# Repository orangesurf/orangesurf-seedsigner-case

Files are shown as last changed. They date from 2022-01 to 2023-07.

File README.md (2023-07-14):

# OrangeSurf SeedSigner Case
Case for the seed signer DIY bitcoin hardware wallet by OrangeSurf (https://orange.surf)

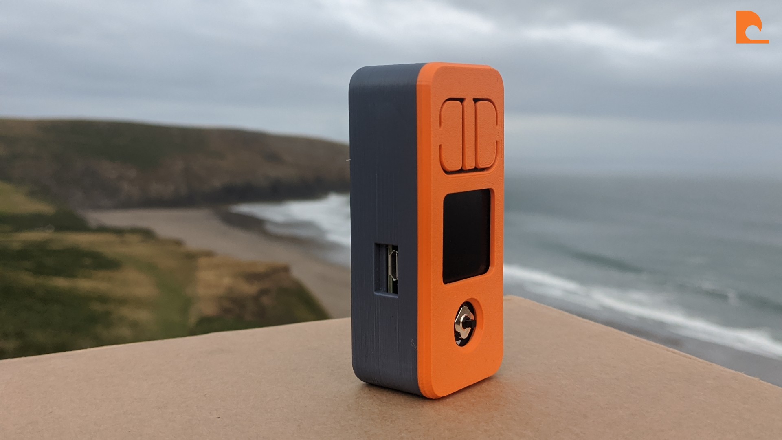
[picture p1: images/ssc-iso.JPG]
ssc-iso


## Donations 
Donations are accepted in bitcoin: https://tips.orange.surf/apps/akitb1oDHpfr1EyVbyiXtEGGgBF/crowdfund

# Files & Documentation 
- [stl files](/stl)
- [step files](/step)
- [Version information](/CHANGES.md)
- [Licence information](/LICENCE.md)

For Version information see https://github.com/orangesurf/orangesurf-seedsigner-case/blob/main/CHANGES.md

For Licence information see https://github.com/orangesurf/orangesurf-seedsigner-case/blob/main/LICENCE.md

For General information see https://github.com/orangesurf/orangesurf-seedsigner-case/blob/main/README.md

# Latest Version Information
- v06 is a 2 part design using live button hinges

# Assembly
- M2 brass inserts should be fitted using a soldering iron into the coverPlate
- M2 countersunk screws (20mm Length) are inserted into the holes in the underside of the outerCase

# Printer Settings
Parts are designed for printing without support on a Prusa MK3S with 0.6mm nozzle at the following settings
- Print cover plate upside down (on flat face). 0.10mm confrmed to work
- Print outer case upright (on flat face). 0.10mm confirmed to work. 

# Camera
V06 is compatible with both the ZeroCam and the more common large pi camera boards.

# PCB Separation Distance
The case is designed for hammer header pins.

# Historic Versions
- v01 for FDM
- v02 is v01 modified for SLA (thinner walls)
- v03-beta is v02 modified for FDM printing 
- v04 is live hinge button version with screw assembly
- v05 switches charging port to power only microUSB
- v06 moves the D-Pad hole for better hole concentricity with joystick axis

https://github.com/orangesurf/orangesurf-seedsigner-case/

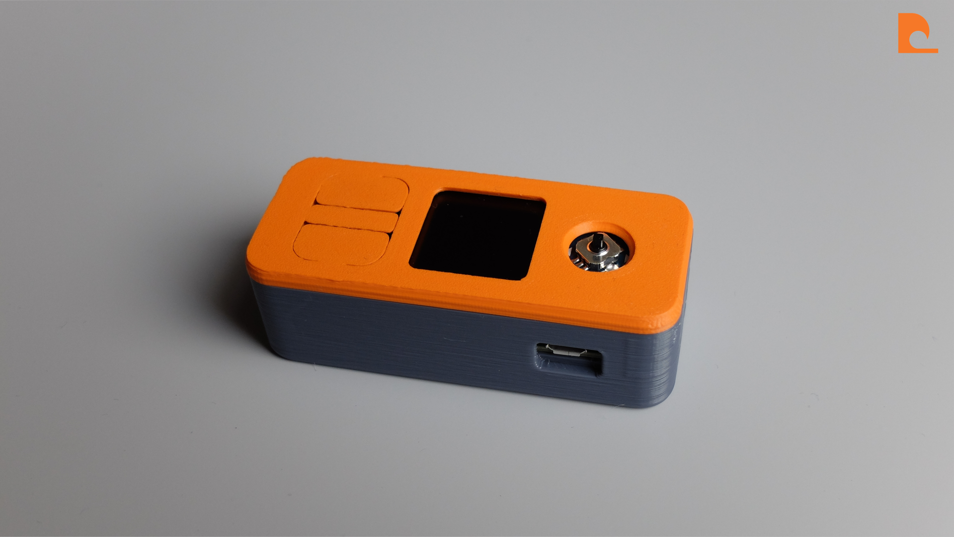
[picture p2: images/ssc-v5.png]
ssc-v5


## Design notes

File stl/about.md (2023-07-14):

For Version information see https://github.com/orangesurf/orangesurf-seedsigner-case/blob/main/CHANGES.md

For Licence information see https://github.com/orangesurf/orangesurf-seedsigner-case/blob/main/LICENCE.md

For General information see https://github.com/orangesurf/orangesurf-seedsigner-case/blob/main/README.md

# Important Version Information
Suggested Version: V06

- v01 for FDM
- v02 is v01 modified for SLA (thinner walls)
- v03-beta is v02 modified for FDM printing 
- v04 is live hinge button version with screw assembly
- v05 switches charging port to power only microUSB
- v06 moves the D-Pad hole for better hole concentricity with joystick axis

# Printer Settings
Parts are confirmed to assemble readily when printed on Prusa MK3S with 0.4mm nozzle at the following settings
- Print cover plate upside down (on flat face). 0.10mm confrmed to work
- Print outer case upright (on flat face). 0.10mm confirmed to work. 

For V01-V03 
- Print all buttons upside down (on flat face) at lowest layer height possible. 0.05mm confirmed to work

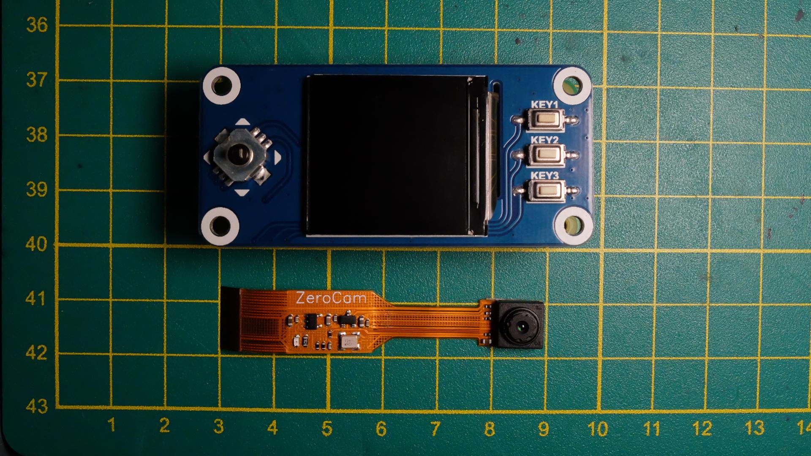
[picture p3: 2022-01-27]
images/ssc-camera.JPG

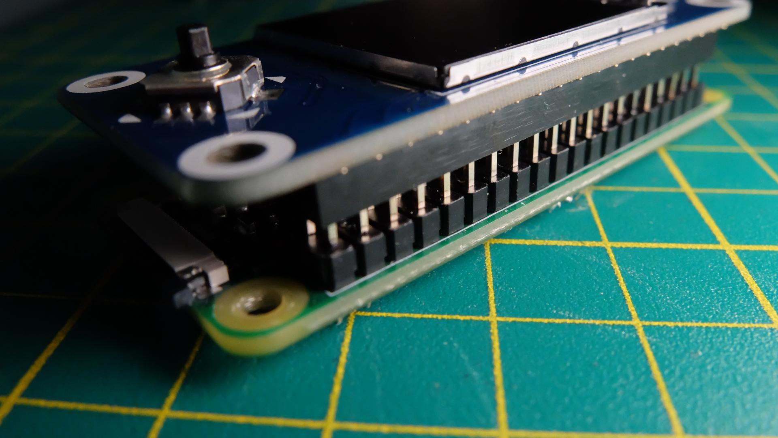
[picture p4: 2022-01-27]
images/ssc-gpio-pins.JPG

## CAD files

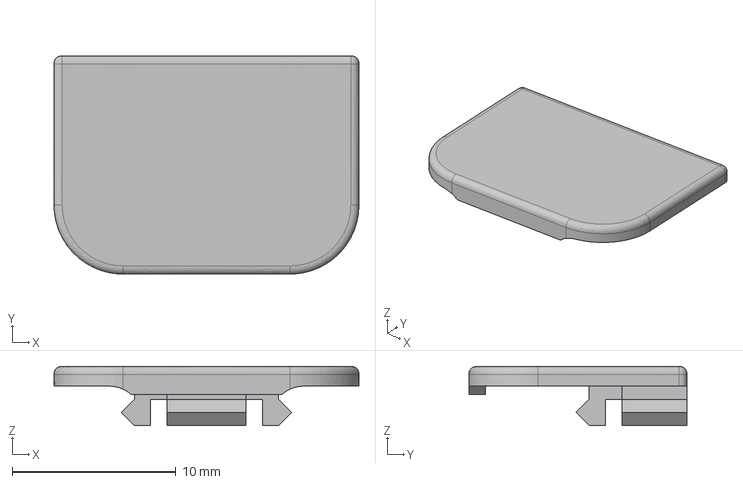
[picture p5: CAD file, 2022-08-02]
step/v03beta/buttonUp-v03.step
18.6 x 13.3 x 3.60 mm

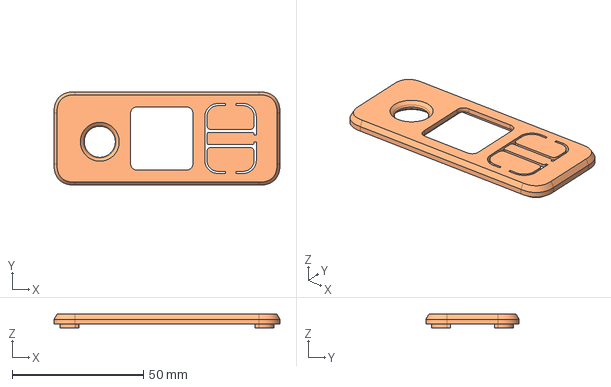
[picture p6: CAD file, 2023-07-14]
step/v06/coverPlate-v06.step
86.0 x 35.5 x 5.30 mm

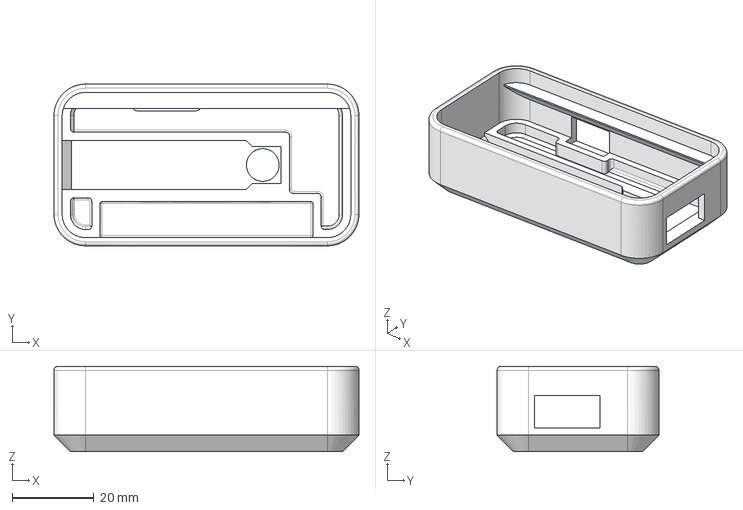
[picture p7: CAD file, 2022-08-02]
step/v03beta/outerCase-v03.step
74.5 x 39.5 x 20.8 mm

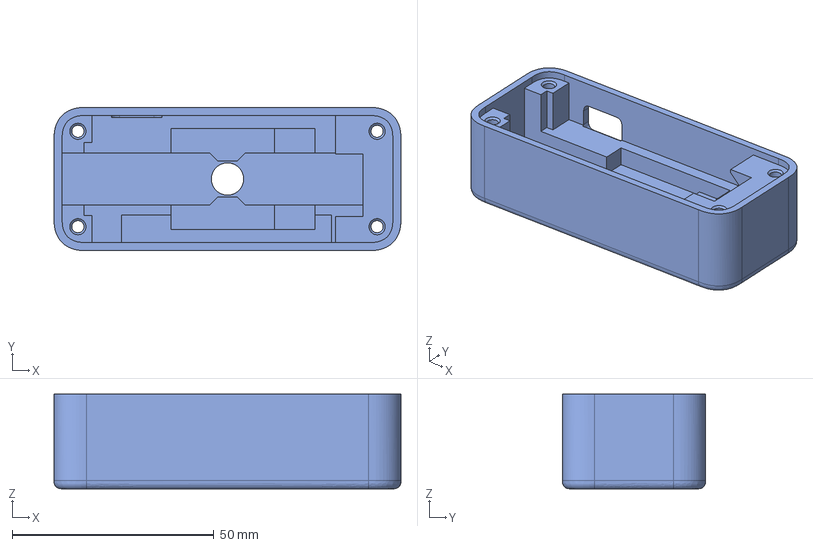
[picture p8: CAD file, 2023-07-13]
step/v06/outerCase-v06.step
86.0 x 35.5 x 23.5 mm

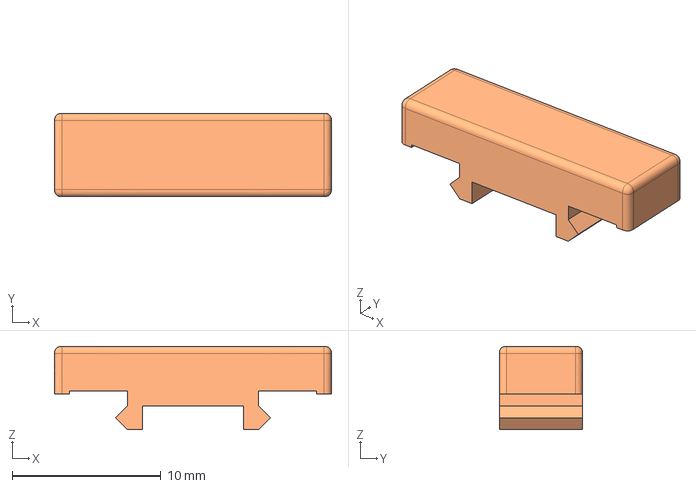
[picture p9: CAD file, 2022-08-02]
step/v03beta/buttonCenter-v03.step
18.6 x 5.60 x 5.60 mm

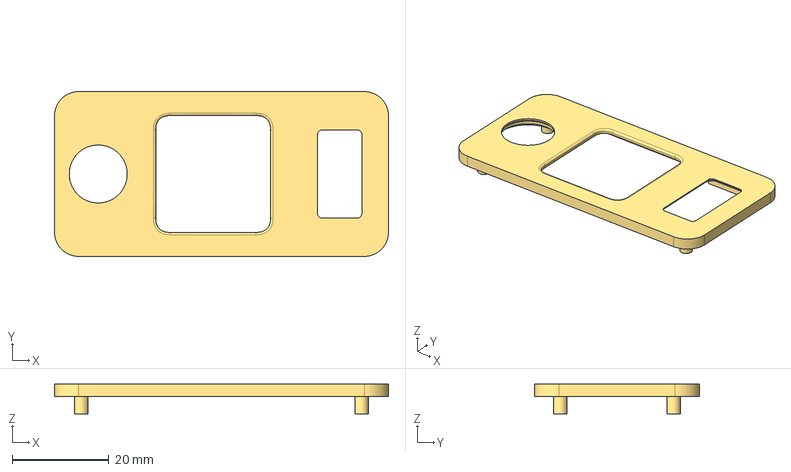
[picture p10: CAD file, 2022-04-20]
step/v03beta/coverPlate-v03.step
69.1 x 34.1 x 6.20 mm

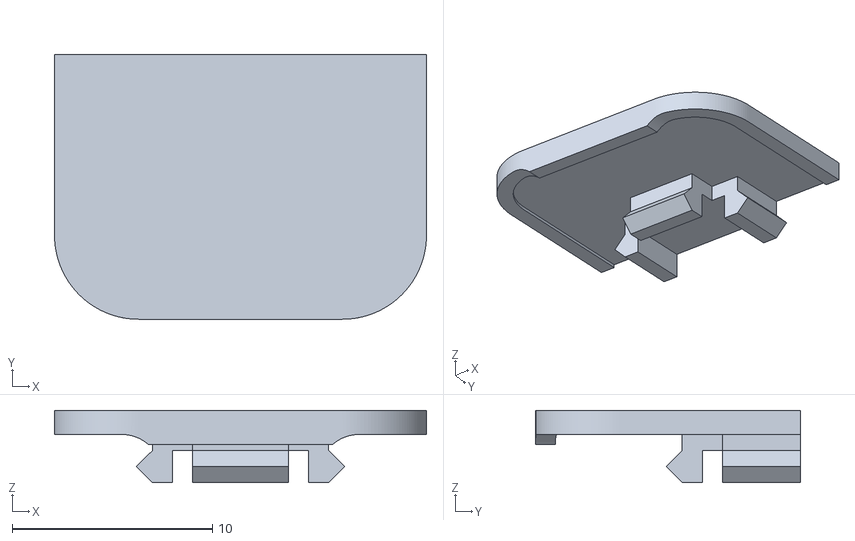
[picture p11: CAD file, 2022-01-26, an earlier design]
stl/v01/upButton-v01.stl
18.6 x 13.2 x 3.60

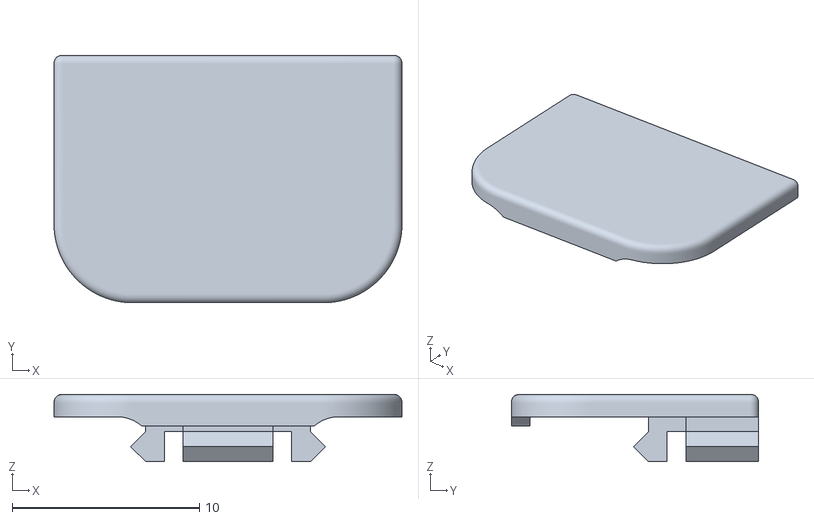
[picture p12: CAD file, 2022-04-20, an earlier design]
stl/v02/buttonTop-v02.stl
18.6 x 13.2 x 3.60

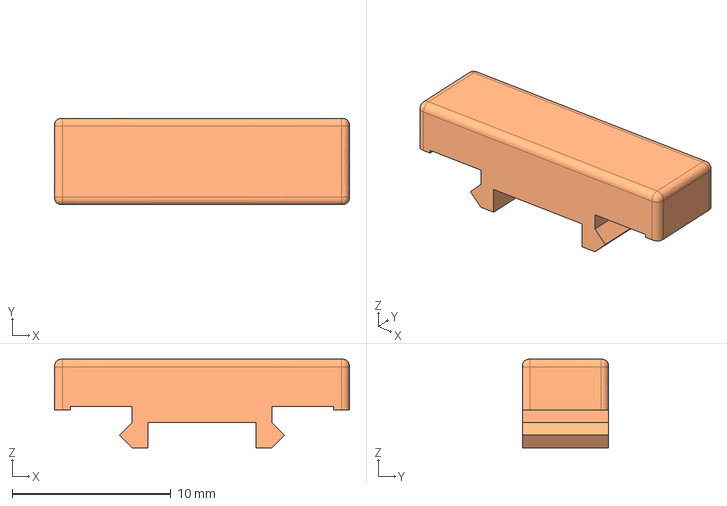
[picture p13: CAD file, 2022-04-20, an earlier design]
step/v02/buttonCenter-v02.step
18.6 x 5.45 x 5.60 mm

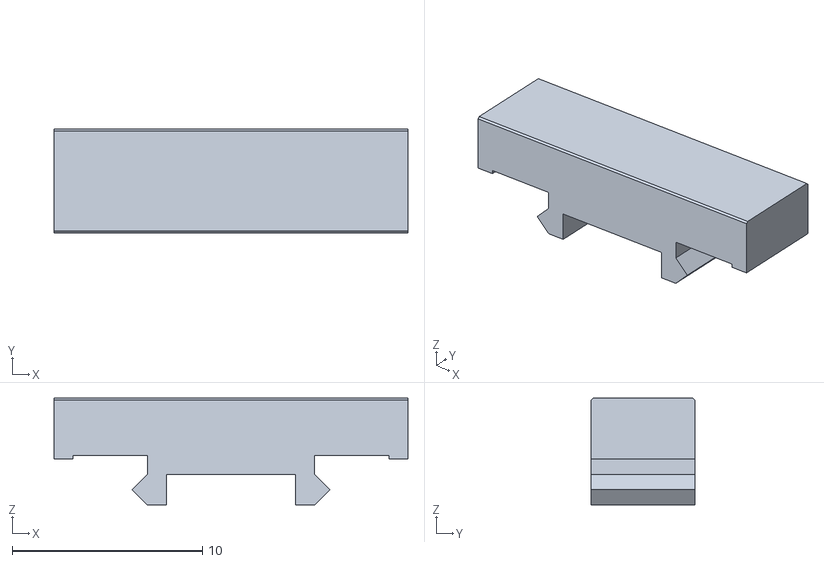
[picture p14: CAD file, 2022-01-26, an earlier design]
stl/v01/centerButton-v01.stl
18.6 x 5.45 x 5.60

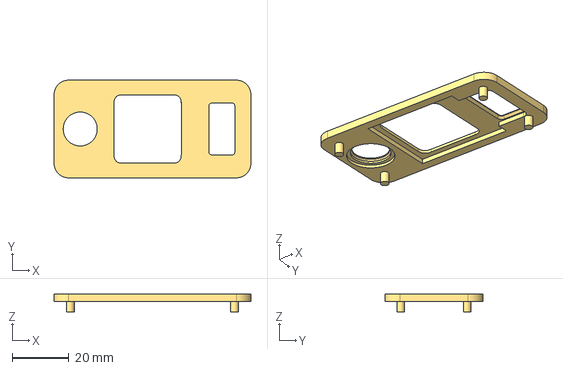
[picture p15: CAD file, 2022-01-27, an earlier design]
step/v01/coverPlate-v01.step
69.5 x 34.5 x 6.20 mm

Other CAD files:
step/v01/buttonDown-v01.step
step/v02/outerCase-v02-experimental.step
step/v04/outerCase-v04.step
step/v05/coverPlate-v05.step
step/v01/buttonUp-v01.step
step/v02/buttonUp-v02.step
step/v01/buttonCenter-v01.step
step/v01/outerCase-v01.step
step/v02/buttonDown-v02.step
step/v02/outerCase-v02.step
stl/v01/coverPlate-v01.stl
stl/v01/outerCase-v01.stl
stl/v02/buttonCenter-v02.stl
stl/v03beta/buttonCenter-v03.stl
stl/v03beta/buttonDown-v03.stl
stl/v03beta/buttonUp-v03.stl
stl/v03beta/coverPlate-v03.stl
stl/v04/outerCase-v04.stl
stl/v05/coverPlate-v05.stl
stl/v06/coverPlate-v06.stl
stl/v06/outerCase-v06.stl

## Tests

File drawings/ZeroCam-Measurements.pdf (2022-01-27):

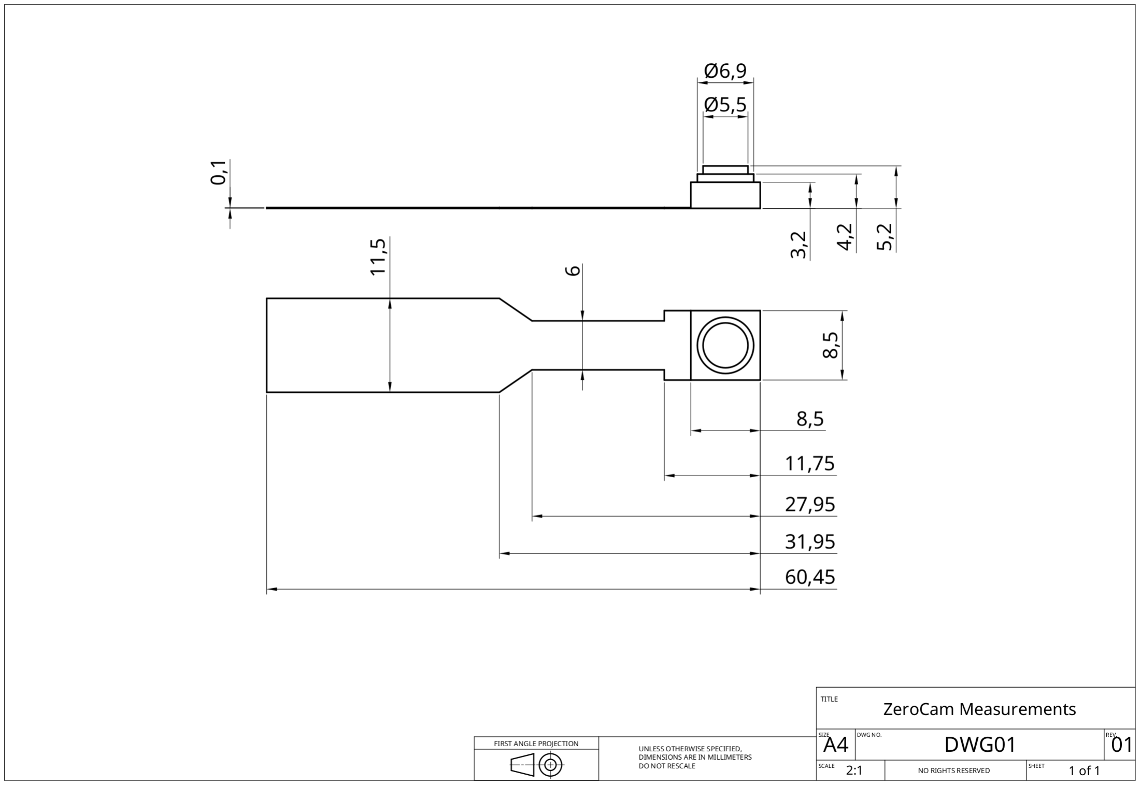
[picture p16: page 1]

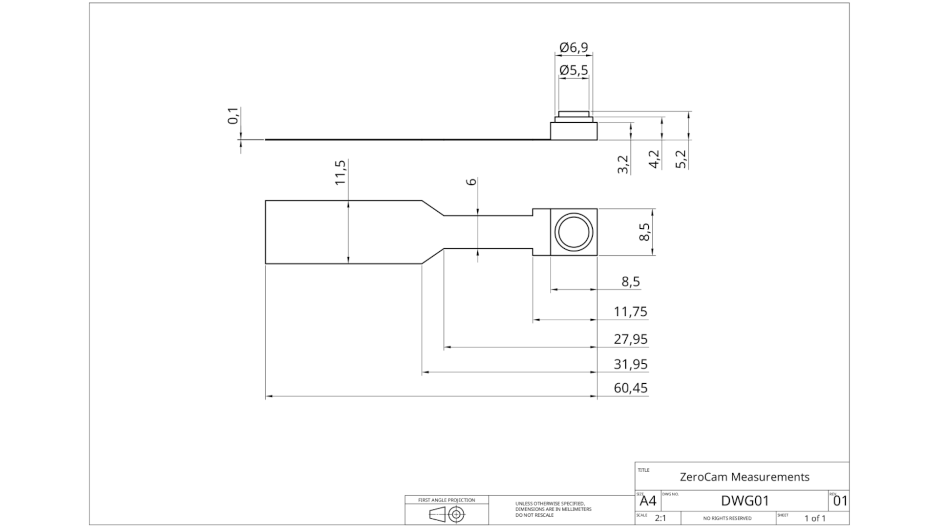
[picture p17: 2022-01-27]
drawings/ZeroCam-Measurements.png

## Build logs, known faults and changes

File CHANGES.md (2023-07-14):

Use this file to document changes made to the designs. 

As per section 3.3.b of the Licence (/Licence/cern_ohl_s_v2.txt), information should be added but NEVER REMOVED from this file. 

When adding information, please provide a brief entry with a date and the nature of the modification for each design change.

# CHANGES:

Date using ISO 8601 (YYYY-MM-DD)

2022-01-26
- Initial release by OrangeSurf (https://orange.surf)

2022-01-27 
- Add step files (OrangeSurf)
- Add drawing of measured ZeroCam camera and links to products
- Modify print settings to include no supports required
- Add the PCB separation distance case is designed for (9mm)

2022-04-20
- Add v02 for SLA printing (STL & STEP files) & update readme / printing guides
- Add v02 experimental outer case (0.6mm wall thickness, down from 2mm)

2022-08-02
- Add v03beta for a common part file for STL & FDM & update readme / printing guides
- Main changes are chamfered outer case lower edge (from rounded) for better FDM prints, decrease gap (0.3 to 0.15mm) between up/down buttons and center button

2023-07-11
- Add v04, switch to 2 part construction using 20mm countersunk M2 bolt & M2 Brass Inserts for assembly
- Compatible with compact and standard camera sizes

2023-07-13
- Add v05, switches charging port to power only microUSB
- Round internal edges of charging port

2023-07-14
- Add v06, moves the D-Pad hole for better hole concentricity with joystick axis

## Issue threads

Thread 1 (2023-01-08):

Missing D-Pad files

ralphreijs, 2023-01-08:
Hi there! Love this design!

Question though: on your website I see images of this case using a Directional Pad button (cross-shaped), yet in the STL and design files I'm missing the files for that D-Pad button.

Would you be able to update your repository to include those?
Thanks a million! 🙏!

[image](https://user-images.githubusercontent.com/203897/211189392-49fbd308-d761-403e-ad3e-8090bf4e162e.jpeg)

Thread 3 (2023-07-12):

pwr-only usb, and microsd access?

jdlcdl, 2023-07-12:
It's a beautiful case, but some considerations that come to mind:

* It looks like the full-featured usb port is available, instead of the pwr-only usb port exclusively.

* The most recent seedsigner release, and those into the future, allow pulling the microsd as soon as seedsigner boots, so that there is no possibility of anything being stored permanently while loading seeds, but it would need to be accessible while seedsigner is assembled.

* It seems like the names on the STL files are swapped, clicking the body gets user to the cover, and vice versa.

Beautiful case!  Nice work!  All the best!

orangesurf, 2023-07-14:
Thanks @jdlcdl

- Switched to pwr-only usb port exclusively in v5 (&v6)
- Intention with this design was that people would be able to glue the screws into position making disassembly for an evil maid attack obvious. I could explore a version which enables easy removal of the microsd in the future.
- The names are correct in the latest release (v6)

Thank you for your help

Closed 2023-07-14.

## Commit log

2022-04-20 Add v02 (SLA version)
    [buttonCenter-v01.step, buttonCenter-v02.step, buttonCenter-v02.stl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]
2022-04-20 Add v02 experimental (0.6mm wall thickness)
    [outerCase-v02-experimental.step]
2022-08-02 Add v03beta (Common FDM/SLA version)
    [buttonCenter-v03.step, buttonCenter-v03.stl, buttonDown-v03.step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]
2023-07-11 Add V04
    [coverPlate-v04.step, coverPlate-v04.stl, outerCase-v04.step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]
